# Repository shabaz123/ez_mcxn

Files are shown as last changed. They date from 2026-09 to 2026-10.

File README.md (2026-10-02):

# EZ-MCXN

This repository contains NXP MCXN related content.

# MCXN236 Test Board

This test board is intended for trying out the MCXN236VKLT microcontroller (100-pin HLQFP 0.5 mm package). The 235 variant is also possible, and there's a good chance the MCXN547VKLT microcontroller will work too.

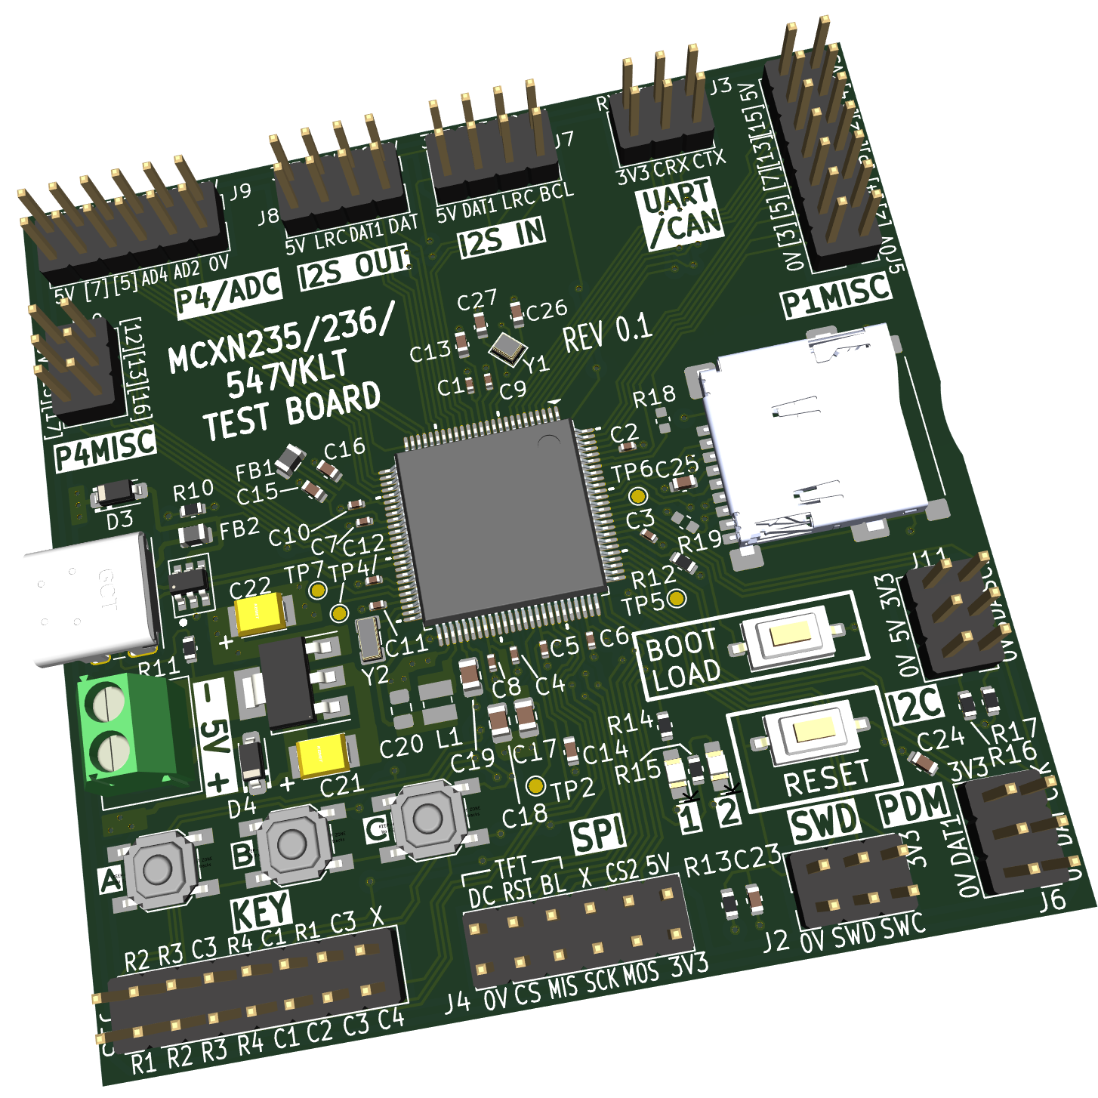
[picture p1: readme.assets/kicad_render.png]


# MCX Projects

This folder contains a board config and example blinky application source code. The folders may be hard-coded in places; the mcx\_projects folder can be placed at `c:\dev\projects` to keep things seamless, otherwise you may need to edit files.

# Environment Variables

The following user vars (environment variables) may need to be created:

`ARMGCC_DIR = C:\DEV\arm_gnu_toolchains\15.2.rel1 `(this folder should contain bin, include, lib folders and so on)

`MCUXPRESSO_SDK_ROOT = C:\dev\projects\mcuxpresso-sdk\mcuxsdk`

# Double Blinky

## Overview

Double Blinky is a simple MCUXpresso SDK project that blinks two LEDs.

The example uses:

* LED1: P3_6
* LED2: P3_1

Both LEDs are active high.

The project also provides a simple starting point for creating new projects using the EZ-MCXN board configuration.

## Prerequisites

The following are required:

* MCUXpresso SDK installed under `C:\dev\projects\mcuxpresso-sdk`
* Arm GNU Toolchain
* CMake and Ninja
* Python
* MCUXpresso Config Tools
* `west`

The project workspace is expected to be:

```text
C:\dev\projects\mcx_projects
```

For example:

```text
C:\dev\projects\mcx_projects\
├── _boards\
│   └── ez_mcxn\
└── double_blinky\
```

The `MCUXPRESSO_SDK_ROOT` environment variable must point to the MCUXpresso SDK:

```text
C:\dev\projects\mcuxpresso-sdk\mcuxsdk
```

## Building the Project

Open PowerShell in the project directory:

```powershell
cd C:\dev\projects\mcx_projects\double_blinky
```

For a clean build:

```powershell
.\build.ps1 pristine
```

The build output is placed in:

```text
double_blinky\output
```

The main generated files are:

```text
output\double_blinky.elf
output\double_blinky.bin
```

Useful build commands are:

```powershell
.\build.ps1
.\build.ps1 clean
.\build.ps1 pristine
.\build.ps1 menuconfig
.\build.ps1 list
```

The commands have the following purposes:

* `.\build.ps1` — Builds the project using the existing build configuration. This is normally the quickest command to use after changing source code.
* `.\build.ps1 clean` — Cleans compiled files from the existing build, then allows the project to be rebuilt.
* `.\build.ps1 pristine` — Deletes the existing build configuration and creates it again from scratch. Use this after changing board files, Kconfig settings or CMake files, or if a normal build behaves unexpectedly.
* `.\build.ps1 menuconfig` — Opens the interactive Kconfig configuration interface, allowing SDK and project configuration options to be viewed or changed.
* `.\build.ps1 list` — Displays the project/build configuration being used by the script, such as the board, SDK, toolchain and build directory.

For normal source-code changes, `.\build.ps1` is usually sufficient. Use `pristine` after changing the board configuration, Kconfig files or CMake files.

## Creating a New Project

`double_blinky` can be used as a template for another application.

Copy the project folder and give it a new name. For example:

```text
C:\dev\projects\mcx_projects\testproj
```

Then:

1. In `CMakeLists.txt`, change the project name from `double_blinky` to `testproj`.
2. In `Kconfig`, change the displayed project name.
3. Modify `main.c` for the new application.
4. Build with:

```powershell
.\build.ps1 pristine
```

The existing `ez_mcxn` board configuration can be shared by multiple projects.

## Board Configuration

Board configurations are stored in:

```text
C:\dev\projects\mcx_projects\_boards
```

The board used by this project is:

```text
C:\dev\projects\mcx_projects\_boards\ez_mcxn
```

The important files include:

```text
ez_mcxn\
├── board\
├── board.c
├── board.h
├── CMakeLists.txt
├── EZ_MXCN.mex
├── Kconfig
├── Kconfig.defconfig
├── prj.conf
└── variable.cmake
```

The `board` subfolder contains files generated by MCUXpresso Config Tools, such as:

```text
clock_config.c
clock_config.h
peripherals.c
peripherals.h
pin_mux.c
pin_mux.h
```

Do not normally edit these generated files manually.

## Adding or Modifying Peripherals

Launch MCUXpresso Config Tools and open:

```text
C:\dev\projects\mcx_projects\_boards\ez_mcxn\EZ_MXCN.mex
```

Use Config Tools to modify pins, clocks and peripherals.

When finished, use **Update Code** to regenerate the files in the `board` subfolder.

Then rebuild the application:

```powershell
.\build.ps1 pristine
```

## Creating a New Board Configuration

If a project needs different hardware without changing the shared `ez_mcxn` configuration, make a copy of the board folder.

For example:

```text
C:\dev\projects\mcx_projects\_boards\myboard
```

Update the board name where required, particularly in:

```text
Kconfig
variable.cmake
board.h
```

Rename the `.mex` file if desired, open it with MCUXpresso Config Tools, make the required pin, clock and peripheral changes, and run **Update Code**.

Finally, change the `$Board` setting in the project's `build.ps1`:

```powershell
$Board = "myboard"
```

Then perform a pristine build.

## EZ-MCXN Hardware

The current EZ-MCXN configuration uses:

* MCU: MCXN236
* Main crystal: 24 MHz
* RTC crystal: 32.768 kHz
* System clock: 150 MHz
* LED1: P3_6, active high
* LED2: P3_1, active high
* UART RX: P1_8
* UART TX: P1_9
* UART: LP_FLEXCOMM4 / LPUART
* UART baud rate: 115200

## Debugging and Programming

### Using a Debug Probe

A compatible SWD debug probe, for example MCU-Link, can be used for programming and debugging.

Build the project first using:

```powershell
.\build.ps1 pristine
```

The ELF file for debugging/programming is then available at:

```text
output\double_blinky.elf
```

### Programming Without a Debug Probe

The MCXN236 contains a ROM-based ISP (In-System Programming) bootloader. This makes it possible to program the internal flash without an SWD debug probe.

The ROM bootloader supports several communication interfaces, including USB HID.

The EZ-MCXN board has a USB connector connected to the MCU USB signals and push-buttons labelled `BOOT LOAD` and `RESET`.

To enter ROM ISP mode:

1. Connect the EZ-MCXN USB connector to the PC.
2. Press and hold `BOOT LOAD`.
3. While continuing to hold `BOOT LOAD`, press and release `RESET`.
4. Release `BOOT LOAD`.

The MCXN236 should now be running its built-in ROM ISP bootloader rather than the application in flash.

The PC can communicate with the ROM bootloader using NXP's `blhost` command-line utility or MCUXpresso Secure Provisioning Tool.

A useful first test with `blhost` is to ask the bootloader for its version/property information. For USB HID, `blhost` uses the USB VID/PID of the ROM bootloader.

For example, the MCXN236 ROM ISP used on NXP's FRDM-MCXN236 is accessible with:

```powershell
blhost -u 0x1FC9,0x0158 -- get-property 1
```

If this succeeds, the PC is communicating with the MCXN236 ROM bootloader.

The application binary produced by this project is:

```text
output\double_blinky.bin
```

For an unsecured development device using the normal internal-flash boot configuration, firmware can be written to the beginning of internal flash using the ROM ISP tools.

NXP's MCUXpresso Secure Provisioning Tool is recommended when initially setting up or verifying this process because it provides a GUI for selecting the MCXN236, establishing the ISP connection, preparing the image and programming the device.

After programming is complete, press `RESET` without holding `BOOT LOAD`. The MCU should then boot the application normally from internal flash.

> **Note:** ROM ISP is different from installing a custom USB DFU bootloader. The MCXN236 ROM bootloader is already built into the chip and cannot be accidentally erased with the application. Secure-boot, lifecycle and CMPA configuration can change what the ROM permits, so the simple procedure above assumes an unsecured development device with the normal internal-flash boot configuration.

# EZ_MCXN Pin Allocations
<!-- info: table: widths="6% 16% 6% 18% 6% 21% 6% 21%" -->

| Pin | Use | Pin | Use | Pin | Use | Pin | Use |
| :-- | :--- | :-- | :--- | :-- | :--- | :-- | :--- |
| 1 | UART\_RXD | 26  | HDR\_PORT4 | 51  | SPARE(TP) | 76  | SWDIO |
| 2 | UART\_TXD | 27  | HDR\_PORT4 | 52  | 0V | 77  | SWCLK |
| 3 | CANTX | 28  | HDR\_PORT4 | 53  | N/C | 78  | SWO |
| 4 | CANRX | 29  | HDR\_PORT4 | 54  | 3.3V | 79  | SPARE(TP) |
| 5 | HDR\_PORT1 | 30  | 3.3V via FBEAD | 55  | Cap to 0V | 80  | PDM\_CLM |
| 6 | HDR\_PORT1 | 31  | 3.3V via FBEAD | 56  | TFT\_DC | 81  | PDM\_DAT |
| 7 | HDR\_PORT1 | 32  | 0V | 57  | TFT\_RST  | 82  | BOOT\_BTN\_CAP\_AND\_PULLUP |
| 8 | HDR\_PORT1 | 33  | 0V | 58  | Cap to 0V | 83  | 3.3V |
| 9 | RST (R/C/BTN) | 34  | 3.3V | 59  | 3.3V | 84  | I2C\_SDA |
| 10  | XTAL | 35  | HDR\_PORT4GENERAL | 60  | TFT\_CS | 85  | I2C\_SCL |
| 11  | EXTAL | 36  | HDR\_PORT4GENERAL | 61  | TFT\_BL | 86  | PDM\_DAT1 |
| 12  | Short to 58 | 37  | HDR\_PORT4GENERAL | 62  | KEY\_ROW1 | 87  | SPARE(TP) |
| 13  | 3.3V | 38  | HDR\_PORT4GENERAL | 63  | KEY\_ROW2 | 88  | microSD MOSI |
| 14  | I2S\_A\_BCLK  | 39  | HDR\_PORT4GENERAL | 64  | KEY\_ROW3 | 89  | microSD SCK |
| 15  | I2S\_A\_LRCLK | 40  | USBDP | 65  | KEY\_ROW4 | 90  | microSD MISO |
| 16  | I2S\_B\_DAT | 41  | USBDM | 66  | 3.3V | 91  | microSD CS |
| 17  | I2S\_A\_DAT | 42  | USB\_VBUS | 67  | KEY\_COL1 | 92  | TFT\_MOSI |
| 18  | I2S\_A\_DAT1  | 43  | 0V | 68  | KEY\_COL2 | 93  | TFT\_SCK |
| 19  | I2S\_B\_DAT1  | 44  | 3.3V | 69  | KEY\_COL3 | 94  | TFT\_MISO |
| 20  | I2S\_B\_BCLK  | 45  | NC/DP | 70  | KEY\_COL4 | 95  | HDR\_PORT1 |
| 21  | I2S\_B\_LRCLK | 46  | NC/DM | 71  | I2S\_MCLK | 96  | 3.3V |
| 22  | HDR\_PORT4 | 47  | 3.3V | 72  | LED1 | 97  | HDR\_PORT1 |
| 23  | HDR\_PORT4 | 48  | EXTAL32K | 73  | 3.3V | 98  | HDR\_PORT1 |
| 24  | HDR\_PORT4 | 49  | XTAL32K | 74  | LED2 | 99  | HDR\_PORT1 |
| 25  | HDR\_PORT4 | 50  | N/C | 75  | TFT\_CS2  | 100 | HDR\_PORT1 |

# EZ-MCXN Parts List

Here is the parts list for the EZ-MCXN board:

| Reference | Qty | Value | Description |
| --- | --- | --- | --- |
| R10, R11 | 2 | 5.1k | 0603 Resistor |
| R12, R13, R16, R17 | 4 | 10k | 0603 Resistor |
| R14, R15 | 2 | 1k | 0603 Resistor |
| R20 | 1 | 0R | 0402 zero-ohm Resistor |
| C1-C12, C16 | 13  | 100n | 0402 Ceramic Capacitor X7R |
| C13-C15, C24, C25  | 5 | 1u | 0603 Ceramic Capacitor X7R |
| C17 | 1 | 4.7u | 0805 Ceramic Capacitor X7R |
| C18 | 1 | 2.2u | 0805 Ceramic Capacitor X7R |
| C19 | 1 | 10u | 0805 Ceramic Capacitor X5R 10V |
| C21, C22 | 2 | 10u | Case B Tantalum Capacitor 10V e.g. TPSB106K016R0800 |
| C23 | 1 | 1n | 0603 Ceramic Capacitor |
| C26, C27 | 2 | 4.7p | 0603 Ceramic Capacitor |
| C29 | 1 | 1u | 0805 Ceramic Capacitor |
| D1, D2 | 2 | LED | 0805 LED (0603 fits too) |
| D3, D4 | 2 | 1N4001W | SOD-123 Diode |
| FB1, FB2 | 2 | BLM21AG121SH1D | SMD Ferrite Bead 0805 120 ohm |
| J1 | 1 | USB4085 | USB Type C Receptacle Through-Hole |
| J2-J11 | 1 | Header | Dual Row 2.54mm Pin Header (total 2 x 42 way, cut to required sizes) |
| J12 | 1 | MicroSD_socket | Same Sky MSD-4-A and possibly Molex 5027740891 |
| J13 | 1 | Keypad | 4x4 or 4x3 keypad and 7- or 8-way header pin or socket if required |
| J14 | 1 | Terminal Block | 2-way Screw Terminal Block 3.5 or 3.81mm pitch |
| SW1-SW3 | 3 | SKQGAFE010 | Tact button SMD 5x5mm body 3.7x6.2mm pitch |
| SW4, SW5 | 1 | TS-1101 | Tact button SMD 6x3.6mm |
| U1 | 1 | MCXN236VKLT | NXP  MCXN236/235/547VKLT HLQFP100 |
| U2 | 1 | MIC5209-3.3YS  | 3.3V LDO SOT-223 |
| U3 | 1 | SRV05-4 | ESD Diode Array |
| Y1 | 1 | 830108212309 | Wurth 24MHz Crystal SMD 2016 4-pin 2.0x1.6mm |
| Y2 | 1 | 830009678 | Wurth 32.768kHz Crystal SMD 2-pin 3.2x1.5mm |

# MINI-MCXN Board
The MINI-MCXN is a very cut-down board, with just 8 GPIO exposed via a flat-flex connector, and pads for attaching wires to PDM mics.

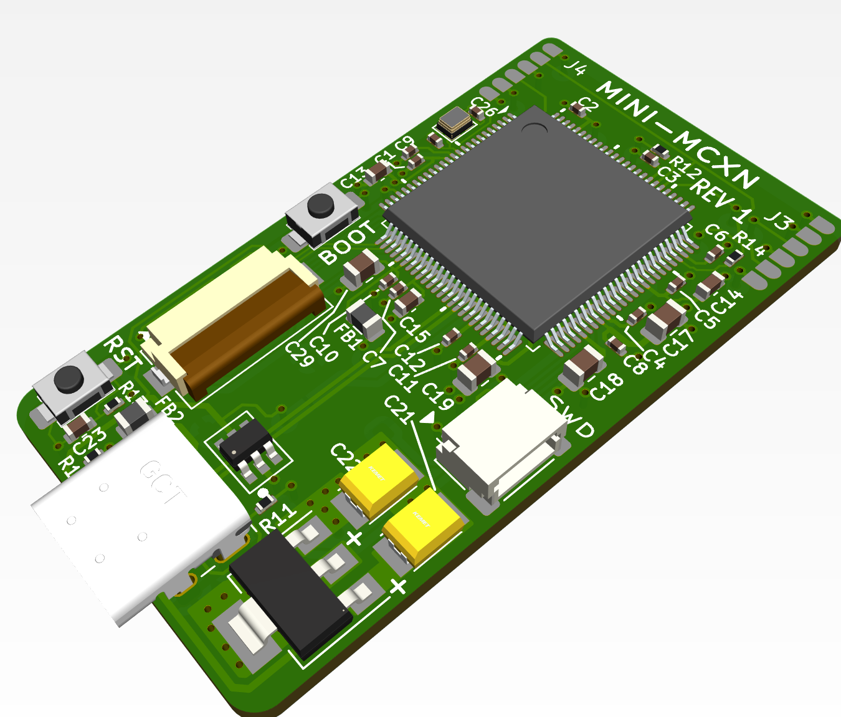
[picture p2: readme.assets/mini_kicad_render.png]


## MINI-MCXN Parts List

| Reference | Qty | Value | Description |
| --- | --- | --- | --- |
| C1-C12 | 12  | 100n | 0402 Capacitor |
| C13-C15 | 3 | 1u | 0603 Capacitor |
| C17 | 1 | 4.7u | 0805 Capacitor |
| C18 | 1 | 2.2u | 0805 Capacitor |
| C19 | 1 | 10u | 0805 Capacitor |
| C21, C22  | 2 | 10u | Case B Tantalum Capacitor 10V e.g. TPSB106K016R0800 |
| C23 | 1 | 1n | 0603 Capacitor |
| C26, C27  | 2 | 4.7p | 0402 Capacitor |
| C29 | 1 | 1u | 0805 Capacitor |
| D1 | 1 | LED | 0603 LED |
| FB1, FB2  | 2 | BLM21AG121SH1D | SMD Ferrite Bead 0805 120 ohm |
| J1 | 1 | USB4085 | USB Type C Receptacle Through-Hole |
| J2 | 1 | JST SH 4-way Conn | Connector JST SH SM04B-SRSS-TB 1mm pitch Horiz |
| J5 | 1 | FFC_0.5MM 16-way  | FFC Connector Hirose FH12-16S-0.5SH 0.5mm pitch Horiz |
| R10, R11  | 2 | 5.1k | 0402 Resistor |
| R12, R13  | 2 | 10k | 0402 Resistor |
| R14 | 1 | 1k | 0402 Resistor |
| SW1-SW3 | 3 | SKQGAFE010 | Tact button SMD 5x5mm body 3.7x6.2mm pitch |
| SW4, SW5  | 2 | Tact 4x3mm | Tact button 4x3mm body 2-pin |
| U1 | 1 | MCXN236VKLT | NXP MCXN236/235/547VKLT HLQFP100 |
| U2 | 1 | MIC5209-3.3YS | 3.3V LDO SOT-223 |
| U3 | 1 | SRV05-4 | ESD Diode Array |
| Y1 | 1 | 830108212309 | Wurth 24MHz Crystal SMD 2016 4-pin 2.0x1.6mm |

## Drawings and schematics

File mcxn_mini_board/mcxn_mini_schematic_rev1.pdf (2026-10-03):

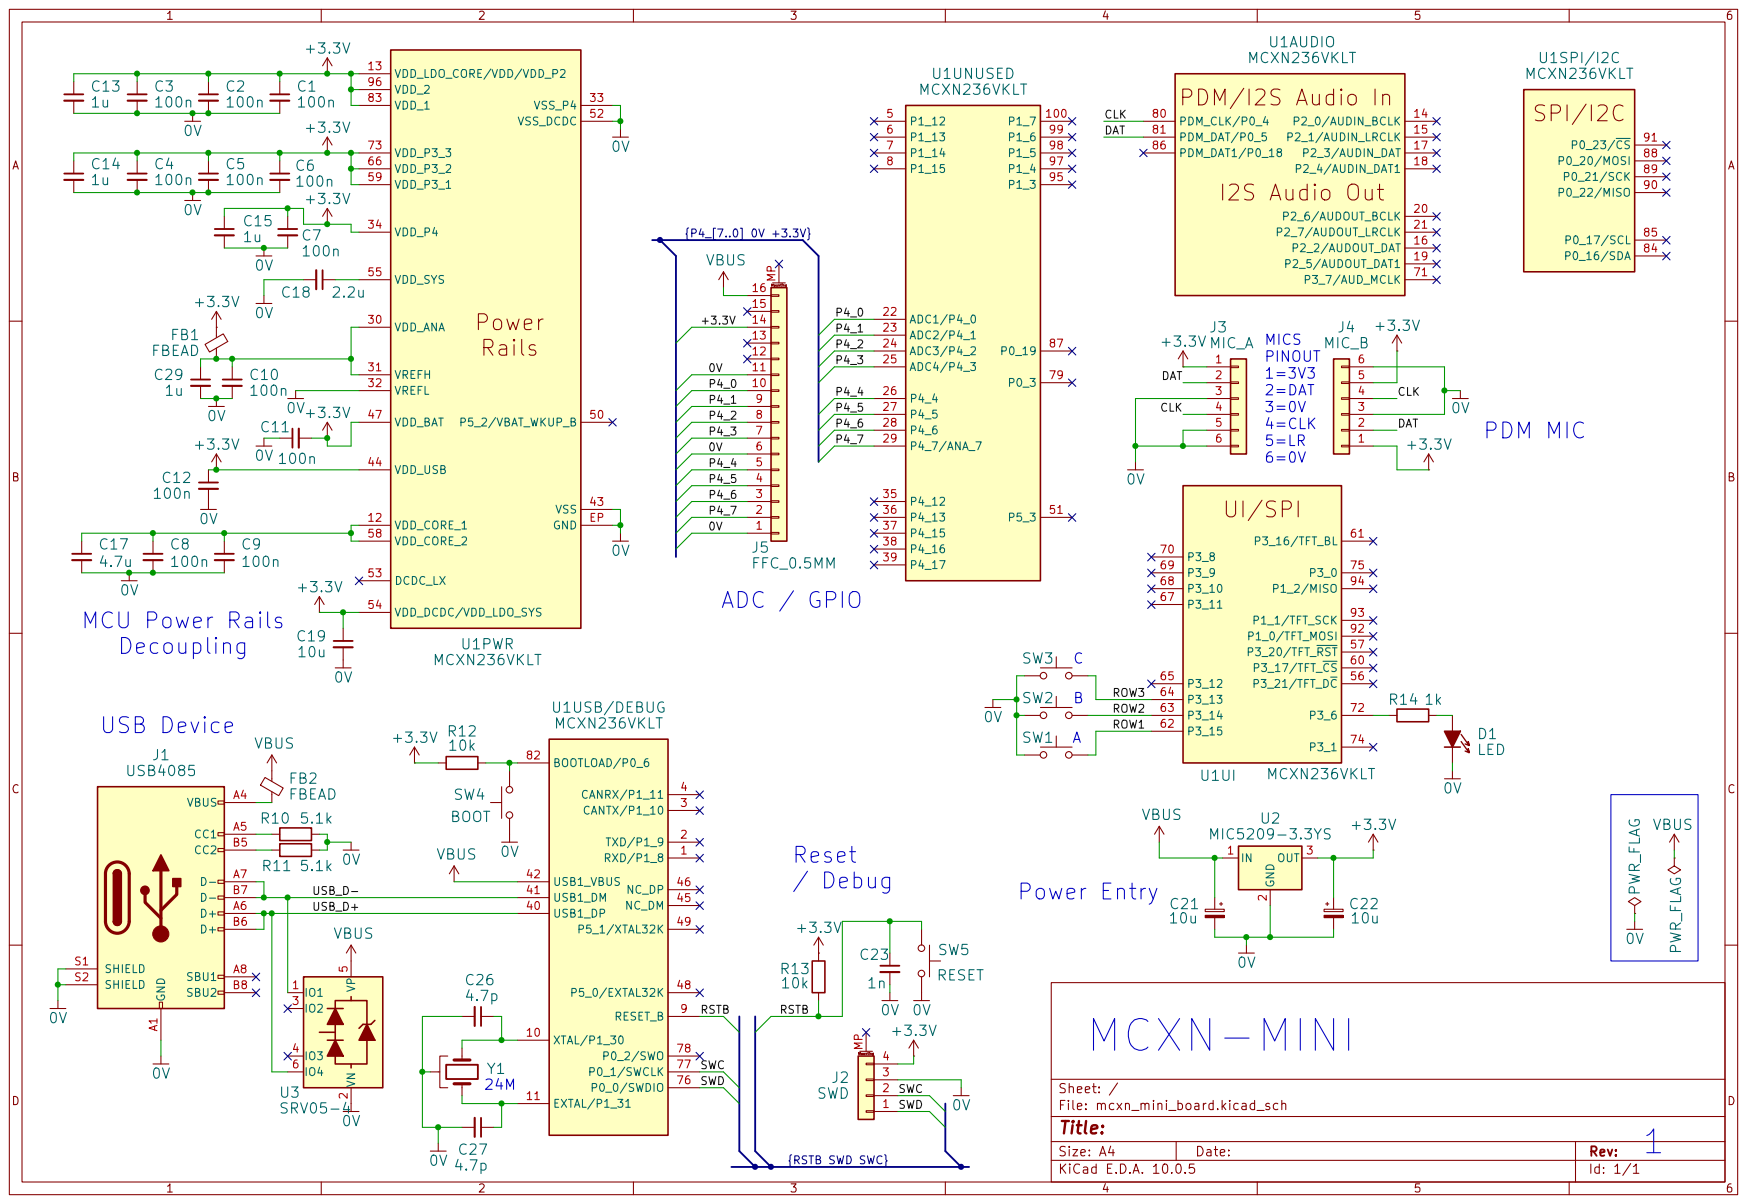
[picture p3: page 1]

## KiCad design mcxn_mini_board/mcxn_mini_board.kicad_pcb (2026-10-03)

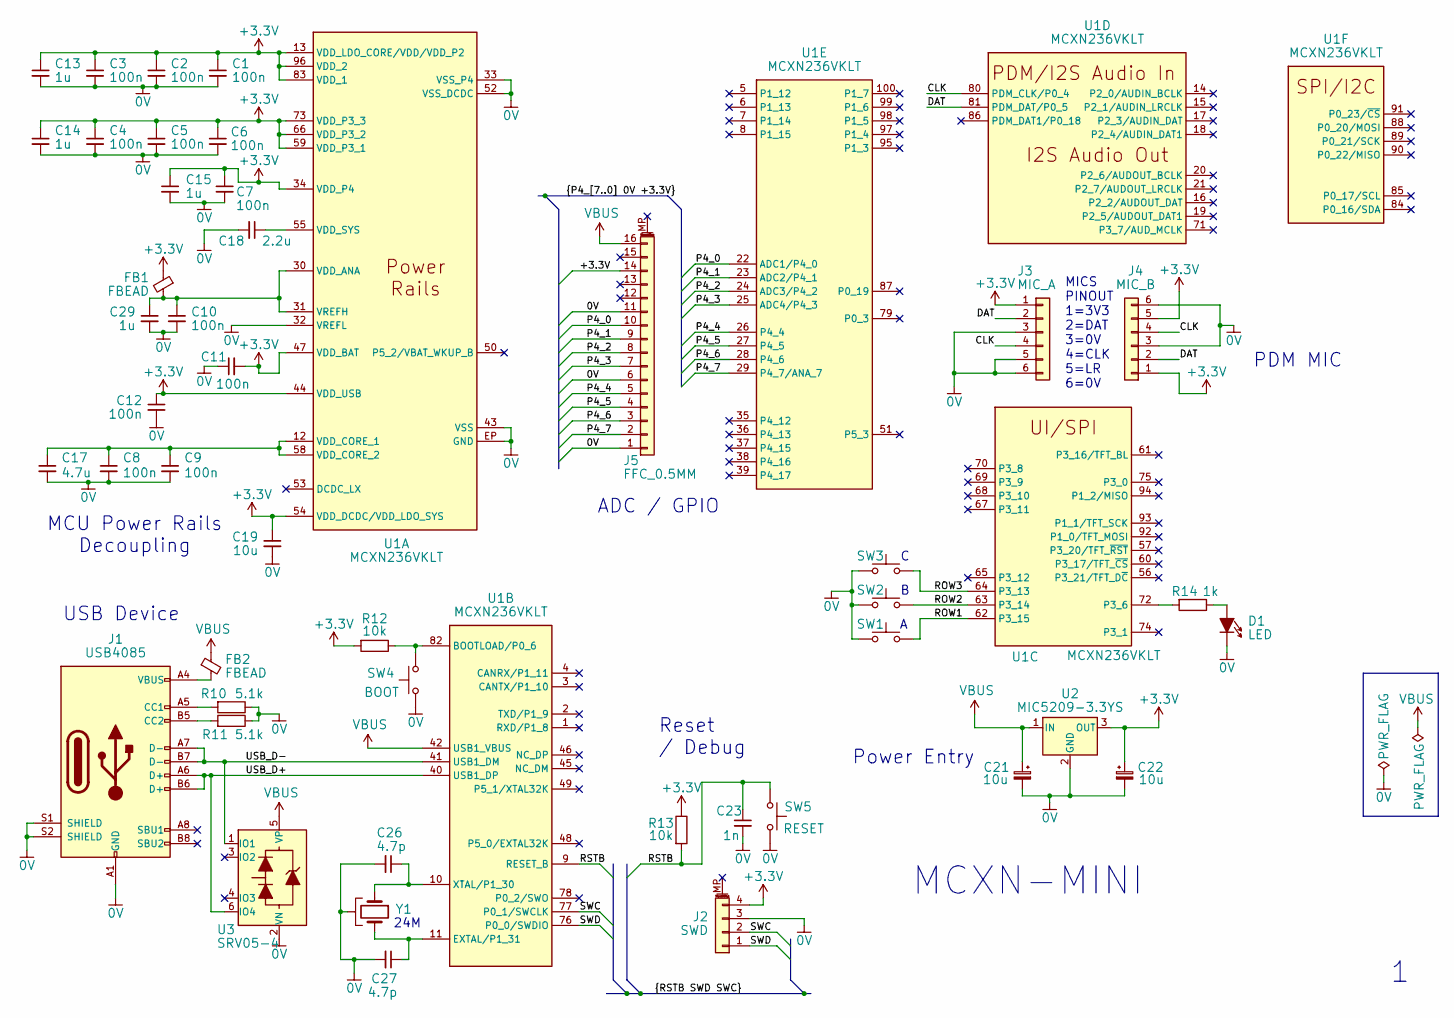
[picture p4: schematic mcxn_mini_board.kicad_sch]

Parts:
C1, C2, C3, C4, C5, C6, C7, C8, C9, C10, C11, C12: 100n; 0402-footprint-improved-Cap3D
C13, C14, C15: 1u; 0603-footprint-improved-Cap3D
C17: 4.7u; C_0805_2012Metric
C18: 2.2u; C_0805_2012Metric
C19: 10u; C_0805_2012Metric
C21, C22: 10u; Cap-Tant-CaseB
C23: 1n; 0603-footprint-improved-Cap3D
C26, C27: 4.7p; 0402-footprint-improved-Cap3D
C29: 1u; C_0805_2012Metric
D1: LED; LED_0603
FB1, FB2: FBEAD; BLM21AG121SH1D
J1: USB4085; USB_C_Receptacle_GCT_USB4085_improved; LCSC Part # C36936564
J2: SWD; JST_SH_SM04B-SRSS-TB_1x04-1MP_P1.00mm_Horizontal
J3: MIC_A; Pad_for_flex_1x06_P1.27mm
J4: MIC_B; Pad_for_flex_1x06_P1.27mm
J5: FFC_0.5MM; Hirose_FH12-16S-0.5SH_1x16-1MP_P0.50mm_Horizontal
R10, R11: 5.1k; 0402-footprint-improved-Res3D; LCSC Part # C723526
R12, R13: 10k; 0402-footprint-improved-Res3D; LCSC Part # C723526
R14: 1k; 0402-footprint-improved-Res3D; LCSC Part # C723526
SW1, SW2, SW3: SKQGAFE010; Tact-SW-TS-1101-6mm-3.6mm
SW4: BOOT; Tact-SW-4x3mm-body
SW5: RESET; Tact-SW-4x3mm-body
U1: MCXN236VKLT; HLQFP100-NXP; Manufacturer_Part_Number MCXN236VKLT; Mouser Part Number 771-MCXN236VKLT
U2: MIC5209-3.3YS; SOT-223
U3: SRV05-4
Y1: 830108212309; Crystal_SMD_2016-4Pin_2.0x1.6mm

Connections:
0V: C1.2, C2.2, C3.2, C4.2, C5.2, C6.2, C7.2, C8.2, C9.2, C10.2, C11.1, C12.2, C13.2, C14.2, C15.2, C17.2, C18.2, C19.2, C21.2, C22.2, C23.2, C26.2, C27.2, C29.2, D1.1 (K), J1.A1 (GND), J1.A12 (GND), J1.B1 (GND), J1.B12 (GND), J1.S1 (SHIELD), J1.S2 (SHIELD), J2.3, J3.3, J3.5, J3.6, J4.3, J4.6, J5.1, J5.6, J5.11, R10.1, R11.1, SW1.1, SW2.1, SW3.1, SW4.1, SW5.1, U1.32 (VREFL), U1.33 (VSS_P4), U1.43 (VSS), U1.52 (VSS_DCDC), U1.EP (GND), U2.2 (GND), U3.2 (VN), Y1.2, Y1.4 (2)
+3.3V: C1.1, C2.1, C3.1, C4.1, C5.1, C6.1, C7.1, C11.2, C12.1, C13.1, C14.1, C15.1, C19.1, C22.1, FB1.1, J2.4, J3.1, J4.1, J4.5, J5.14, R12.2, R13.1, U1.13 (VDD_LDO_CORE/VDD/VDD_P2), U1.34 (VDD_P4), U1.44 (VDD_USB), U1.47 (VDD_BAT), U1.54 (VDD_DCDC/VDD_LDO_SYS), U1.59 (VDD_P3_1), U1.66 (VDD_P3_2), U1.73 (VDD_P3_3), U1.83 (VDD_1), U1.96 (VDD_2), U2.3 (OUT)
/CLK: J3.4, J4.4, U1.80 (PDM_CLK/P0_4)
/DAT: J3.2, J4.2, U1.81 (PDM_DAT/P0_5)
/P4_0: J5.10, U1.22 (ADC1/P4_0)
/P4_1: J5.9, U1.23 (ADC2/P4_1)
/P4_2: J5.8, U1.24 (ADC3/P4_2)
/P4_3: J5.7, U1.25 (ADC4/P4_3)
/P4_4: J5.5, U1.26 (P4_4)
/P4_5: J5.4, U1.27 (P4_5)
/P4_6: J5.3, U1.28 (P4_6)
/P4_7: J5.2, U1.29 (P4_7/ANA_7)
/ROW1: SW1.2, U1.62 (P3_15)
/ROW2: SW2.2, U1.63 (P3_14)
/ROW3: SW3.2, U1.64 (P3_13)
/RSTB: C23.1, R13.2, SW5.2, U1.9 (RESET_B)
/SWC: J2.2, U1.77 (P0_1/SWCLK)
/SWD: J2.1, U1.76 (P0_0/SWDIO)
/USB_D+: J1.A6 (D+), J1.B6 (D+), U1.40 (USB1_DP), U3.6 (IO4)
/USB_D-: J1.A7 (D-), J1.B7 (D-), U1.41 (USB1_DM), U3.1 (IO1)
unnamed: D1.2 (A), R14.1
unnamed: FB2.2, J1.A4 (VBUS), J1.A9 (VBUS), J1.B4 (VBUS), J1.B9 (VBUS)
unnamed: J1.A5 (CC1), R10.2
unnamed: J1.B5 (CC2), R11.2
unnamed: C10.1, C29.1, FB1.2, U1.30 (VDD_ANA), U1.31 (VREFH)
unnamed: C8.1, C9.1, C17.1, U1.12 (VDD_CORE_1), U1.58 (VDD_CORE_2)
unnamed: C18.1, U1.55 (VDD_SYS)
unnamed: R14.2, U1.72 (P3_6)
unnamed: R12.1, SW4.2, U1.82 (BOOTLOAD/P0_6)
unnamed: C27.1, U1.11 (EXTAL/P1_31), Y1.3
unnamed: C26.1, U1.10 (XTAL/P1_30), Y1.1
VBUS: C21.1, FB2.1, J5.16, U1.42 (USB1_VBUS), U2.1 (IN), U3.5 (VP)

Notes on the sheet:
Reset / Debug
MCU Power Rails Decoupling
24M
MCXN-MINI
ADC / GPIO
MICS PINOUT 1=3V3 2=DAT 3=0V 4=CLK 5=LR 6=0V
PDM MIC
USB Device
Power Entry

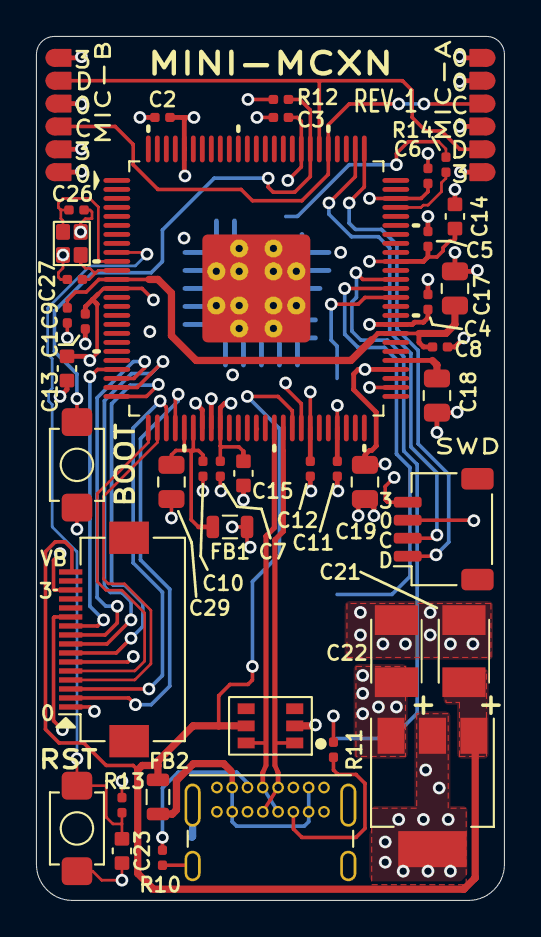
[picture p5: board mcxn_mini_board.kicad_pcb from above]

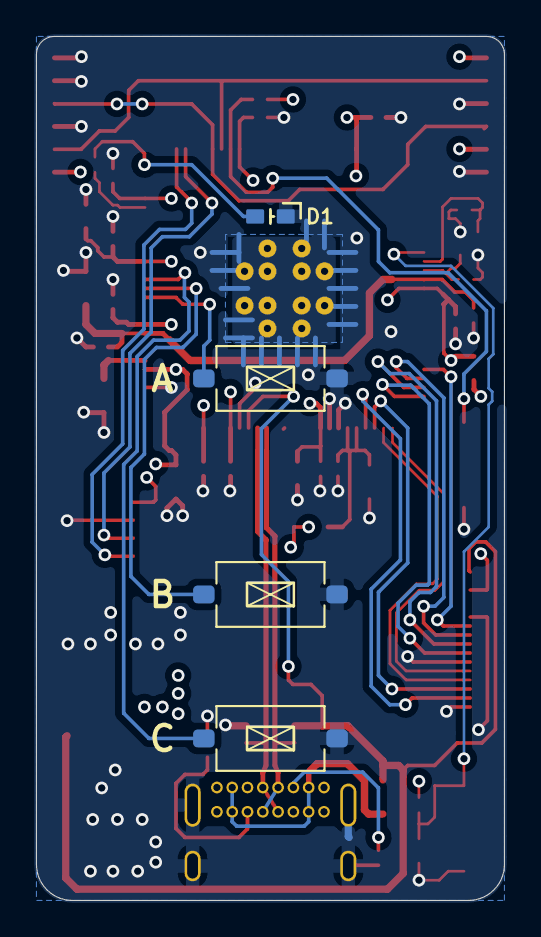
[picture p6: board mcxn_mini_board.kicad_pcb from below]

Board: 4 copper layers, 26.0 x 48.0 mm, 46 parts (4 on the bottom side), 32 nets.

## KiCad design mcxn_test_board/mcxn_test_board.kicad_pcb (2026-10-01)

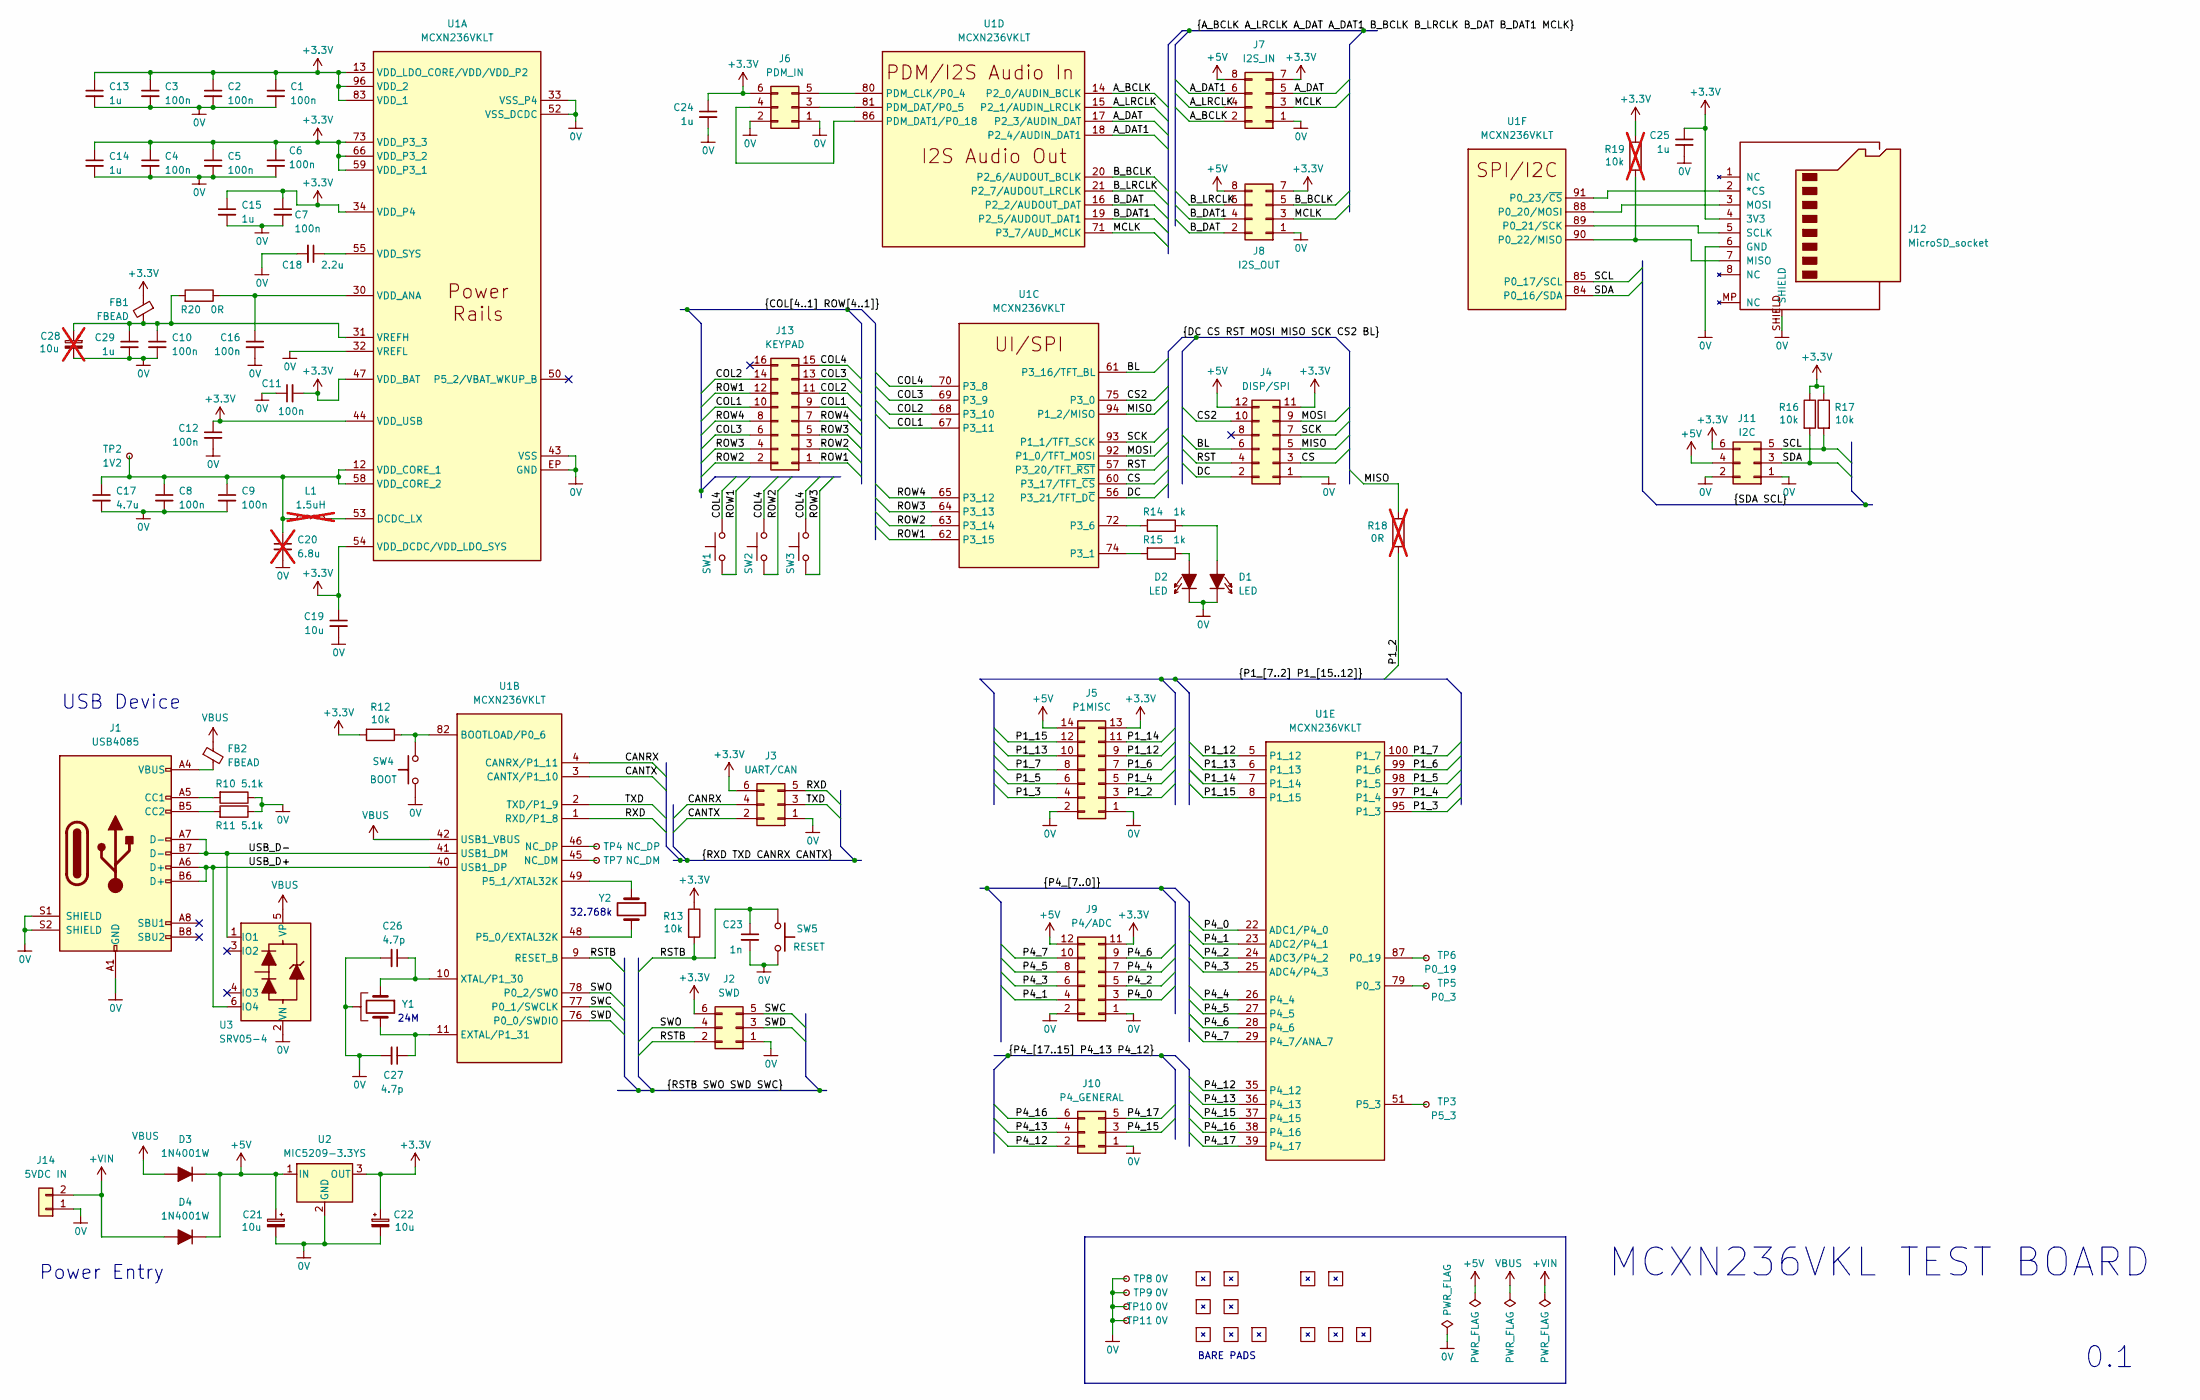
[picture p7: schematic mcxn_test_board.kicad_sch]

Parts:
C1, C2, C3, C4, C5, C6, C7, C8, C9, C10, C11, C12, C16: 100n; 0402-footprint-improved-Cap3D
C13, C14, C15, C24, C25: 1u; 0603-footprint-improved-Cap3D
C17: 4.7u; C_0805_2012Metric
C18: 2.2u; C_0805_2012Metric
C19: 10u; C_0805_2012Metric
C20: 6.8u; C_0805_2012Metric; not fitted
C21, C22: 10u; Cap-Tant-CaseB
C23: 1n; 0603-footprint-improved-Cap3D
C26, C27: 4.7p; 0603-footprint-improved-Cap3D
C28: 10u; Cap-Tant-CaseB; not fitted
C29: 1u; C_0805_2012Metric
D1, D2: LED; LED_0603_or_0805
D3, D4: 1N4001W; D_SOD-123-pins12
FB1, FB2: FBEAD; BLM21AG121SH1D
J1: USB4085; USB_C_Receptacle_GCT_USB4085_improved; LCSC Part # C36936564
J2: SWD; PinHeader_2x03_P2.54mm_Vertical
J3: UART/CAN; PinHeader_2x03_P2.54mm_Vertical
J4: DISP/SPI; PinHeader_2x06_P2.54mm_Vertical
J5: P1MISC; PinHeader_2x07_P2.54mm_Vertical
J6: PDM_IN; PinHeader_2x03_P2.54mm_Vertical
J7: I2S_IN; PinHeader_2x04_P2.54mm_Vertical
J8: I2S_OUT; PinHeader_2x04_P2.54mm_Vertical
J9: P4/ADC; PinHeader_2x06_P2.54mm_Vertical
J10: P4_GENERAL; PinHeader_2x03_P2.54mm_Vertical
J11: I2C; PinHeader_2x03_P2.54mm_Vertical
J12: MicroSD_socket; microsd-generic
J13: KEYPAD; PinHeader_2x08_P2.54mm_Vertical
J14: 5VDC IN; TerminalBlock_2way-3.5-3.81mm
L1: 1.5uH; L_Bourns-SRN2510; not fitted
R10, R11: 5.1k; 0603-footprint-improved-Res3D; LCSC Part # C723526
R12, R13, R16, R17: 10k; 0603-footprint-improved-Res3D; LCSC Part # C723526
R14, R15: 1k; 0603-footprint-improved-Res3D; LCSC Part # C723526
R18: 0R; 0603-footprint-improved-Res3D; LCSC Part # C723526; not fitted
R19: 10k; 0603-footprint-improved-Res3D; LCSC Part # C723526; not fitted
R20: 0R; 0402-footprint-improved-Res3D; LCSC Part # C723526
SW1, SW2, SW3: SKQGAFE010
SW4: BOOT; Tact-SW-TS-1101-6mm-3.6mm; LCSC Part # C500065
SW5: RESET; Tact-SW-TS-1101-6mm-3.6mm; LCSC Part # C500065
TP2: 1V2; TestPoint_Pad_D1.0mm
TP3: P5_3; TestPoint_Pad_D1.0mm
TP4: NC_DP; TestPoint_Pad_D1.0mm
TP5: P0_3; TestPoint_Pad_D1.0mm
TP6: P0_19; TestPoint_Pad_D1.0mm
TP7: NC_DM; TestPoint_Pad_D1.0mm
TP8, TP9, TP10, TP11: 0V; TestPoint_Plated_Hole_0.6mm
U1: MCXN236VKLT; HLQFP100-NXP; Manufacturer_Part_Number MCXN236VKLT; Mouser Part Number 771-MCXN236VKLT
U2: MIC5209-3.3YS; SOT-223
U3: SRV05-4
U4, U5, U9, U13, U16, U17: bare-pad-3x3
U6, U7: bare-pad-2x2
U8, U10, U11, U14: bare-pad-2x1
Y1: 830108212309; Crystal_SMD_2016-4Pin_2.0x1.6mm
Y2: 830009678; Crystal_SMD-2Pin_3.2x1.5mm

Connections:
0V: C1.2, C2.2, C3.2, C4.2, C5.2, C6.2, C7.2, C8.2, C9.2, C10.2, C11.1, C12.2, C13.2, C14.2, C15.2, C16.2, C17.2, C18.2, C19.2, C20.2, C21.2, C22.2, C23.2, C24.2, C25.2, C26.2, C27.2, C28.2, C29.2, D1.1 (K), D2.1 (K), J1.A1 (GND), J1.A12 (GND), J1.B1 (GND), J1.B12 (GND), J1.S1 (SHIELD), J1.S2 (SHIELD), J2.1, J3.1, J4.1, J5.1, J5.2, J6.1, J6.2, J7.1, J8.1, J9.1, J9.2, J10.1, J11.1, J11.2, J12.6 (GND), J12.SHIELD, J14.1, R10.1, R11.1, SW4.1, SW5.1, TP8.1 (1_1), TP9.1 (1_1), TP10.1 (1_1), TP11.1 (1_1), U1.32 (VREFL), U1.33 (VSS_P4), U1.43 (VSS), U1.52 (VSS_DCDC), U1.EP (GND), U2.2 (GND), U3.2 (VN), Y1.2, Y1.4 (2)
+3.3V: C1.1, C2.1, C3.1, C4.1, C5.1, C6.1, C7.1, C11.2, C12.1, C13.1, C14.1, C15.1, C19.1, C22.1, C24.1, C25.1, FB1.1, J2.6, J3.6, J4.11, J5.13, J6.6, J7.7, J8.7, J9.11, J11.6, J12.4 (3V3), R12.2, R13.1, R16.1, R17.1, R19.1, U1.13 (VDD_LDO_CORE/VDD/VDD_P2), U1.34 (VDD_P4), U1.44 (VDD_USB), U1.47 (VDD_BAT), U1.54 (VDD_DCDC/VDD_LDO_SYS), U1.59 (VDD_P3_1), U1.66 (VDD_P3_2), U1.73 (VDD_P3_3), U1.83 (VDD_1), U1.96 (VDD_2), U2.3 (OUT)
+5V: C21.1, D3.1 (K), D4.1 (K), J4.12, J5.14, J7.8, J8.8, J9.12, J11.4, U2.1 (IN)
+VIN: D4.2 (A), J14.2
/A_BCLK: J7.2, U1.14 (P2_0/AUDIN_BCLK)
/A_DAT: J7.5, U1.17 (P2_3/AUDIN_DAT)
/A_DAT1: J7.6, U1.18 (P2_4/AUDIN_DAT1)
/A_LRCLK: J7.4, U1.15 (P2_1/AUDIN_LRCLK)
/BL: J4.6, U1.61 (P3_16/TFT_BL)
/B_BCLK: J8.5, U1.20 (P2_6/AUDOUT_BCLK)
/B_DAT: J8.2, U1.16 (P2_2/AUDOUT_DAT)
/B_DAT1: J8.4, U1.19 (P2_5/AUDOUT_DAT1)
/B_LRCLK: J8.6, U1.21 (P2_7/AUDOUT_LRCLK)
/CANRX: J3.4, U1.4 (CANRX/P1_11)
/CANTX: J3.2, U1.3 (CANTX/P1_10)
/COL1: J13.9, J13.10, U1.67 (P3_11)
/COL2: J13.11, J13.14, U1.68 (P3_10)
/COL3: J13.6, J13.13, U1.69 (P3_9)
/COL4: J13.15, SW1.2, SW2.2, SW3.2, U1.70 (P3_8)
/CS: J4.3, U1.60 (P3_17/TFT_~CS)
/CS2: J4.10, U1.75 (P3_0)
/DC: J4.2, U1.56 (P3_21/TFT_D~C)
/MCLK: J7.3, J8.3, U1.71 (P3_7/AUD_MCLK)
/MISO: J4.5, R18.1, U1.94 (P1_2/MISO)
/MOSI: J4.9, U1.92 (P1_0/TFT_MOSI)
/P1_2: J5.3, R18.2
/P1_3: J5.4, U1.95 (P1_3)
/P1_4: J5.5, U1.97 (P1_4)
/P1_5: J5.6, U1.98 (P1_5)
/P1_6: J5.7, U1.99 (P1_6)
/P1_7: J5.8, U1.100 (P1_7)
/P1_12: J5.9, U1.5 (P1_12)
/P1_13: J5.10, U1.6 (P1_13)
/P1_14: J5.11, U1.7 (P1_14)
/P1_15: J5.12, U1.8 (P1_15)
/P4_0: J9.3, U1.22 (ADC1/P4_0)
/P4_1: J9.4, U1.23 (ADC2/P4_1)
/P4_2: J9.5, U1.24 (ADC3/P4_2)
/P4_3: J9.6, U1.25 (ADC4/P4_3)
/P4_4: J9.7, U1.26 (P4_4)
/P4_5: J9.8, U1.27 (P4_5)
/P4_6: J9.9, U1.28 (P4_6)
/P4_7: J9.10, U1.29 (P4_7/ANA_7)
/P4_12: J10.2, U1.35 (P4_12)
/P4_13: J10.4, U1.36 (P4_13)
/P4_15: J10.3, U1.37 (P4_15)
/P4_16: J10.6, U1.38 (P4_16)
/P4_17: J10.5, U1.39 (P4_17)
/ROW1: J13.1, J13.12, SW1.1, U1.62 (P3_15)
/ROW2: J13.2, J13.3, SW2.1, U1.63 (P3_14)
/ROW3: J13.4, J13.5, SW3.1, U1.64 (P3_13)
/ROW4: J13.7, J13.8, U1.65 (P3_12)
/RST: J4.4, U1.57 (P3_20/TFT_~RST)
/RSTB: C23.1, J2.2, R13.2, SW5.2, U1.9 (RESET_B)
/RXD: J3.5, U1.1 (RXD/P1_8)
/SCK: J4.7, U1.93 (P1_1/TFT_SCK)
/SCL: J11.5, R17.2, U1.85 (P0_17/SCL)
/SDA: J11.3, R16.2, U1.84 (P0_16/SDA)
/SWC: J2.5, U1.77 (P0_1/SWCLK)
/SWD: J2.3, U1.76 (P0_0/SWDIO)
/SWO: J2.4, U1.78 (P0_2/SWO)
/TXD: J3.3, U1.2 (TXD/P1_9)
/USB_D+: J1.A6 (D+), J1.B6 (D+), U1.40 (USB1_DP), U3.6 (IO4)
/USB_D-: J1.A7 (D-), J1.B7 (D-), U1.41 (USB1_DM), U3.1 (IO1)
unnamed: D1.2 (A), R14.1
unnamed: D2.2 (A), R15.1
unnamed: FB2.2, J1.A4 (VBUS), J1.A9 (VBUS), J1.B4 (VBUS), J1.B9 (VBUS)
unnamed: J1.A5 (CC1), R10.2
unnamed: J1.B5 (CC2), R11.2
unnamed: J6.3, U1.81 (PDM_DAT/P0_5)
unnamed: J6.4, U1.86 (PDM_DAT1/P0_18)
unnamed: J6.5, U1.80 (PDM_CLK/P0_4)
unnamed: J12.2 (*CS), U1.91 (P0_23/~CS)
unnamed: J12.7 (MISO), R19.2, U1.90 (P0_22/MISO)
unnamed: J12.3 (MOSI), U1.88 (P0_20/MOSI)
unnamed: J12.5 (SCLK), U1.89 (P0_21/SCK)
unnamed: L1.2, U1.53 (DCDC_LX)
unnamed: C16.1, R20.1, U1.30 (VDD_ANA)
unnamed: C8.1, C9.1, C17.1, C20.1, L1.1, TP2.1 (1_1), U1.12 (VDD_CORE_1), U1.58 (VDD_CORE_2)
unnamed: C18.1, U1.55 (VDD_SYS)
unnamed: C10.1, C28.1, C29.1, FB1.2, R20.2, U1.31 (VREFH)
unnamed: R15.2, U1.74 (P3_1)
unnamed: R14.2, U1.72 (P3_6)
unnamed: TP5.1 (1_1), U1.79 (P0_3)
unnamed: TP6.1 (1_1), U1.87 (P0_19)
unnamed: TP3.1 (1_1), U1.51 (P5_3)
unnamed: R12.1, SW4.2, U1.82 (BOOTLOAD/P0_6)
unnamed: C27.1, U1.11 (EXTAL/P1_31), Y1.3
unnamed: TP7.1 (1_1), U1.45 (NC_DM)
unnamed: TP4.1 (1_1), U1.46 (NC_DP)
unnamed: U1.48 (P5_0/EXTAL32K), Y2.2
unnamed: U1.49 (P5_1/XTAL32K), Y2.1
unnamed: C26.1, U1.10 (XTAL/P1_30), Y1.1
VBUS: D3.2 (A), FB2.1, U1.42 (USB1_VBUS), U3.5 (VP)

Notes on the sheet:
24M
MCXN236VKL TEST BOARD
BARE PADS
0.1
32.768k
USB Device
Power Entry

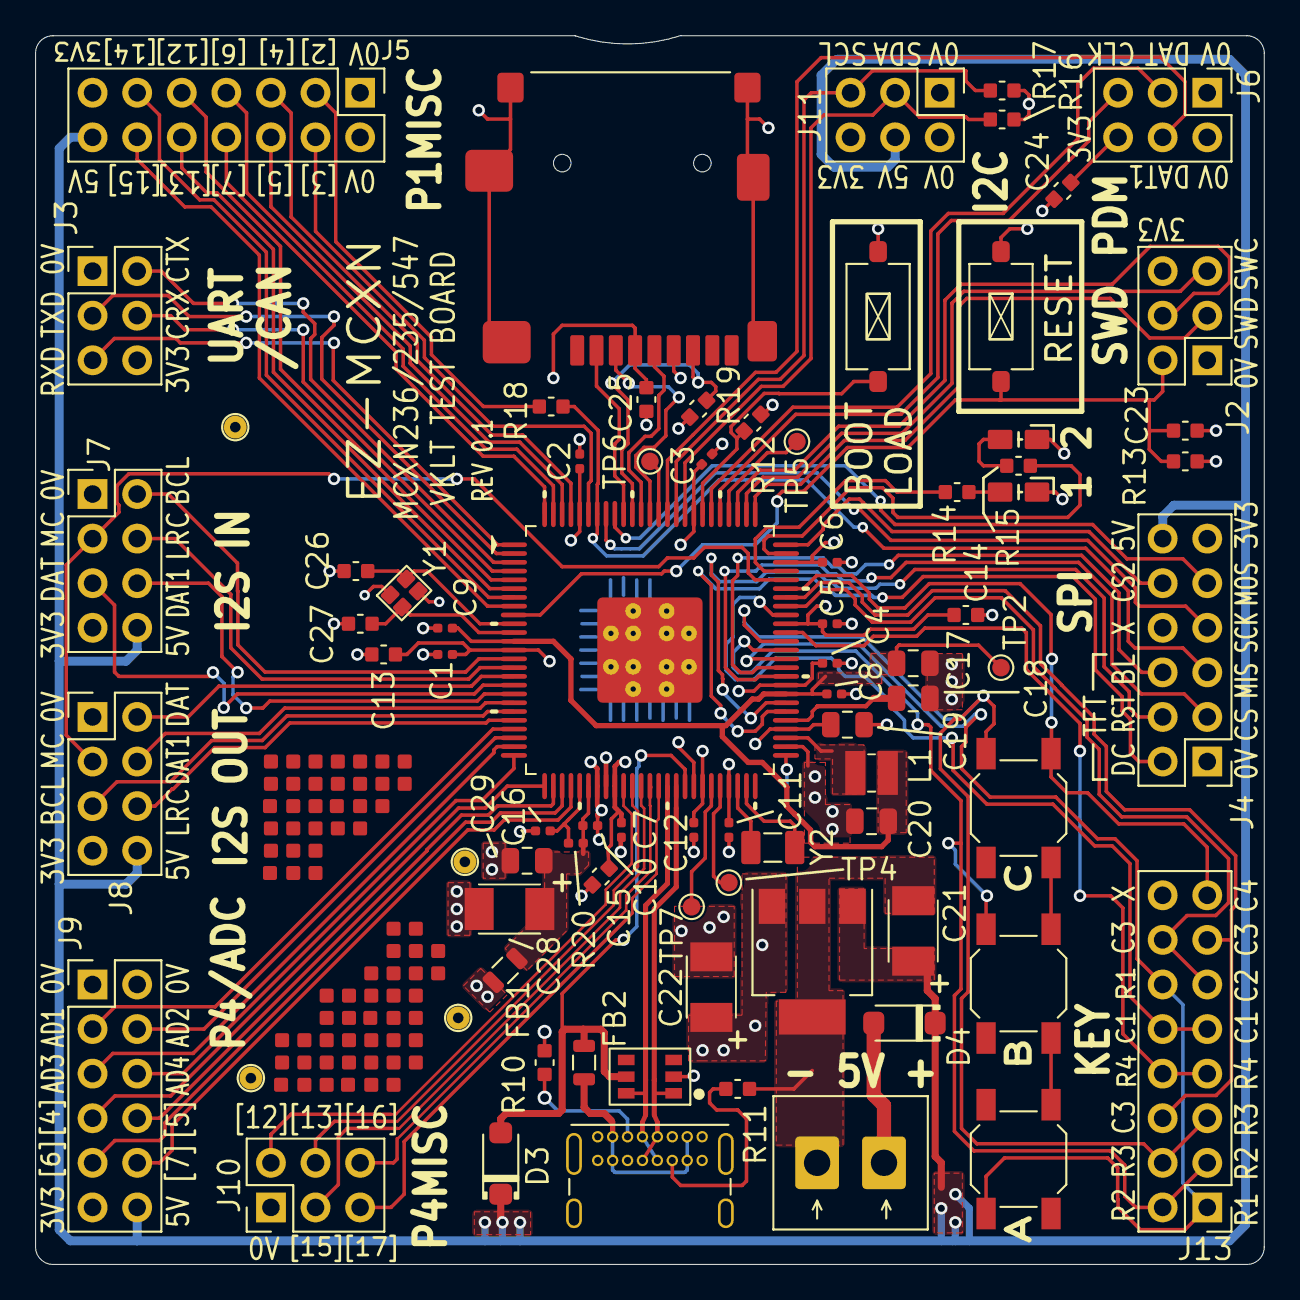
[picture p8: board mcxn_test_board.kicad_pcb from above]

Board: 4 copper layers, 70.0 x 70.0 mm, 93 parts (1 on the bottom side), 94 nets.

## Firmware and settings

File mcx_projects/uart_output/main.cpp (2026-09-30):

/*********************************************
 * uart output
 * rev 1 - shabaz - sep 2026
 * This project transmits text out of the
 * UART
 *********************************************/

#include "board.h"
#include "peripherals.h"
#include <stdio.h>
#include <stdint.h>

extern "C" int _write(int handle, char *buffer, int size)
{
    (void)handle;

    LPUART_WriteBlocking(
        LP_FLEXCOMM4_PERIPHERAL,
        reinterpret_cast<const uint8_t *>(buffer),
        static_cast<size_t>(size)
    );

    return size;
}

void
delay_ms(uint16_t n) {
    for (volatile uint16_t j=0; j<n; j++) {
        for (volatile uint32_t i=0; i<50000U; i++) {
            __NOP();
        }
    }
}

int main(void)
{
    uint16_t count = 0;
    BOARD_InitHardware();

    LED1_ON();
    LED2_OFF();

    while (1)
    {
        printf("count = %d\r\n", count);
        count ++;
        LED1_TOGGLE();
        LED2_TOGGLE();
        delay_ms(500);
    }
}

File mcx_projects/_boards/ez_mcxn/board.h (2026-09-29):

#ifndef _BOARD_H_
#define _BOARD_H_

#include "fsl_gpio.h"
#include "pin_mux.h"


/*******************************************************************************
 * Definitions
 ******************************************************************************/

#define BOARD_NAME "EZ-MCXN"

/* LEDs - active high */
#define BOARD_LED1_GPIO      BOARD_INITPINS_LED1_PIN_GPIO
#define BOARD_LED1_GPIO_PIN  BOARD_INITPINS_LED1_PIN_GPIO_PIN

#define BOARD_LED2_GPIO      BOARD_INITPINS_LED2_PIN_GPIO
#define BOARD_LED2_GPIO_PIN  BOARD_INITPINS_LED2_PIN_GPIO_PIN

#define LOGIC_LED_ON   1U
#define LOGIC_LED_OFF  0U

#define LED1_ON() \
    GPIO_PinWrite(BOARD_LED1_GPIO, BOARD_LED1_GPIO_PIN, LOGIC_LED_ON)

#define LED1_OFF() \
    GPIO_PinWrite(BOARD_LED1_GPIO, BOARD_LED1_GPIO_PIN, LOGIC_LED_OFF)

#define LED1_TOGGLE() \
    GPIO_PortToggle(BOARD_LED1_GPIO, 1U << BOARD_LED1_GPIO_PIN)

#define LED2_ON() \
    GPIO_PinWrite(BOARD_LED2_GPIO, BOARD_LED2_GPIO_PIN, LOGIC_LED_ON)

#define LED2_OFF() \
    GPIO_PinWrite(BOARD_LED2_GPIO, BOARD_LED2_GPIO_PIN, LOGIC_LED_OFF)

#define LED2_TOGGLE() \
    GPIO_PortToggle(BOARD_LED2_GPIO, 1U << BOARD_LED2_GPIO_PIN)

/*******************************************************************************
 * API
 ******************************************************************************/

#if defined(__cplusplus)
extern "C" {
#endif

void BOARD_InitHardware(void);

#if defined(__cplusplus)
}
#endif

#endif /* _BOARD_H_ */
